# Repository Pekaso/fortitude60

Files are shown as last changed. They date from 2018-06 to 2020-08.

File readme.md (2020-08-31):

# Fortitude60

Fortitude60

👊A 60% (12x5) split keyboard with staggerd column layout.👊

# Build Guide

## Fortitude60 v1.0(C94 Limited Edition)
[ビルドガイド（日本語）](Documents/buildguide_jp_v1.0.md)

[Build Guide (EN)](Documents/buildguide_en_v1.0.md)

## Fortitude60 v1.1(Yushakobo Ver.)
[ビルドガイド（日本語）](Documents/buildguide_jp_v1.1.md)

[Build Guide (EN)](Documents/buildguide_en_v1.1.md)

# Firmware Flashing
[ファームウェア書き込み方法（日本語）](Documents/firmware_flashing-jp_new.md)

[Firmware Flashing（EN）](Documents/firmware_flashing-en_new.md)

## F.A.Q
[よくある質問（日本語）](Documents/faq_jp.md)

[Frequently Asked Questions（EN）](Documents/faq_en.md)

# License

Released under the MIT license. see [LICENSE](https://github.com/Pekaso/fortitude60/blob/master/LICENSE)

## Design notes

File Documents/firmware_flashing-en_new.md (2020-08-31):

# Fortitude60 Firmware Burning Instructions (Latest Version)

## Burning Instructions for a Brand New MCU (Applicable for the first time only)
New MCUs do not have any firmware written to them. Follow the instructions below to write the firmware and settings data to the EEPROM for the first time.

These instructions assume you have the QMK Firmware build environment and a firmware burning application, such as AVRDude, installed on your computer.

### First-Time Burning Instructions (Linux, macOS, Msys2 on Windows)
1.  In the same way you would install any other QMK Firmware, navigate into the ``QMK Firmware`` directory and run the commands listed below:
To burn the firmware for the left-hand side of the keyboard: ``make fortitude60/rev1:default:avrdude-split-left``  
To burn the firmware for the right-hand side of the keyboard: ``make fortitude60/rev1:default:avrdude-split-right``

1. When you see the message, ``Detecting USB port, reset your controller now........`` during the build process, create a short between the Reset (RST) and GND pins on the MCU using a pair of tweezers. This will put the MCU into Write Mode. (Note: Be careful not to accidentally touch the nearby 5V pin!)

2. When you see the message, ``avrdude.exe done.  Thank you.``, the firmware has been written successfully.

If you are using Windows 10, after you have completed burning the firmware for the left-hand side of the keyboard, when you navigate to [Bluetooth and Other Devices], under [Settings]-[Devices], the keyboard will appear as ``The Fortitude60 Keyboard``.

settings

If you are using the Current QMK Firmware ([d1190df](https://github.com/qmk/qmk_firmware/commit/d1190df10be933c64fee648b41191131313020a2) or later, you will be able to use this same method to verify the right-hand side of the keyboard. If you are using an earlier version, you will see the message: **No device is recognized**

### Burning Instructions (Windows GUI) 
Please refer to the instructions in: 
[firmware_flashing-en.md#Burning Instructions (Windows)](/Documents/firmware_flashing-jp==en.md#BurningInstructionsWindows) .

## Typical Firmware Burning (Applies from the second time on)

The instructions for burning the firmware from the second time on are always the same. Simply run the following command:

``make fortitude60/rev1:default:avrdude``

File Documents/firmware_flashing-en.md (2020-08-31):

# Fortitude60 Firmware Burning Instructions（Old Version）
These steps are requierd to prepare a MCU for the first time, or to reset it back to the factory settings. If you have bought a v1.0 Kit, the keymap and essential settings have already been written to the MCU, so please proceed with the normal burning instructions (v1.0 users can skip the EEPROM section.) 

These instructions assume you have the QMK Firmware build environment and a firmware burning application, such as AVRDude, installed on your computer.

## Burning the EEPROM
Due to the hardware limitations of the Foritude 60, you must burn separate EEPROMs for the left-hand and right-hand sides of the keyboard, to help identify the devices. After you have written the EEPROM once, you do not need to do it again every time you update the QMK firmware. 

You can find the files that you need to write to the EEPROM in the following location:   
``/qmk_firmware/quantum/split_common``  

This is the file for the left-hand side: ``eeprom-lefthand.eep``  
This is the file forthe right-hand side: ``eeprom-righthand.eep``

### Burning Instructions (Linux)
To put the MCU into Write Mode, when the LED on the chip starts blinking, create a short between the Reset (RST) and GND pins on the MCU using a pair of tweezers, then execute the following commands. (Note: Be careful not to accidentally touch the nearby 5V pin!)

Command for Left-Hand Side of Keyboard:
``avrdude -c avr109 -p m32u4 -P /dev/ttyS1 -U  eeprom:w:"./quantum/split_common/eeprom-lefthand.eep``

Command for Right-Hand Side of Keyboard:
``avrdude -c avr109 -p m32u4 -P /dev/ttyS1 -U  eeprom:w:"./quantum/split_common/eeprom-righthand.eep``

Note: For your installation, replace ``/dev/tty*`` with the serial port name that appears when you reset the MCU.

### Burning Instructions (Windows)
Use AVRDude (GUI-baseed app) according to the directions indicated here:  
http://emizping.hatenablog.com/entry/2017/05/25/222653

This will allow you to burn both QMK firmwares at the same time. 

## Burning the QMK Firmware
You can burn the QMK Firmware for the0 Fortitude 60 in the same manner as any other keyboard: 

``make fortitude60/rev1:default:avrdude``

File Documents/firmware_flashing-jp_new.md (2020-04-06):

# Fortitude60 ファームウェア書き込み方法（最新版）

## 新品のMCUへの書き込み（初回のみ）
新品のMCUにはファームウェアが書き込まれていないため、下記の方法で初期ファームウェアとEEPROMへの設定データを書き込んで下さい。

以下はPCにQMK Firmwareのビルド環境及びAVRDUDEなどの書き込みツールが利用できるようになっていることを前提としています。

### 書き込み方法(Linux, macOS, Msys2 on Windows)
1. 通常のQMK Firmwareと同様に、qmk_firmware直下のディレクトリへ移動し、以下のコマンドを実行してください。  
左手側の書き込み: ``make fortitude60/rev1:default:avrdude-split-left``  
右手側の書き込み: ``make fortitude60/rev1:default:avrdude-split-right``

1. 途中で``Detecting USB port, reset your controller now........``という表示が出たら、MCU上のリセット（RST）ピンとGNDピンをピンセットなどでショート（隣に5Vがあるので注意！）させMCUを書き込みモードにします。

2. ``avrdude.exe done.  Thank you.``がでて正常に終了すれば完了です。

左手側を書き込んだあと、Windows10であれば[Windowsの設定]-[デバイス]の中の[Bluetoothとその他デバイス]欄に``The Fortitude60 Keyboard``というデバイスが認識されていれば成功です。

settings

~~右手側を書き込んだあと、**デバイスとして何も認識されない**のが正しい挙動になります。~~  
(現在のQMK Firmware([d1190df](https://github.com/qmk/qmk_firmware/commit/d1190df10be933c64fee648b41191131313020a2)以降)では右手側もデバイスとして認識されるようになりました。)

### 書き込み方法(Windows GUI)
[firmware_flashing-jp.md#書き込み方法windows](/Documents/firmware_flashing-jp.md#書き込み方法windows) を参照してください。

## 通常のファームウェアの書き込み（2回目以降）
2回目以降のファームウェアの書き換えは他のキーボードと同様に書き込んでください。

``make fortitude60/rev1:default:avrdude``

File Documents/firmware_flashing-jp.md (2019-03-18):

# Fortitude60 ファームウェア書き込み方法（旧版）
MCUを単体で新規購入したり、訳あって再度書き込みしたい場合の手順です。
キット付属品、キーマップ更新などの単純な書き込み時には不要です。通常通りの書き込みを行ってください。

以下はPCにQMK Firmwareのビルド環境及びAVRDUDEなどの書き込みツールが利用できるようになっていることを前提としています。

## EEPROM書き込み
Fortitude60はハードウェアの制約上、左右の識別にEPROMの書き込みが必要です。この手順は新品のMCUに初めて書き込む場合のみ必要です。また一度書き込んだ以降はQMKの書き換えごとに以下を行う必要もありません。

EEPROMに書き込むファイルは以下のディレクトリにあります。  
``/qmk_firmware/quantum/split_common``  

左手用 ``eeprom-lefthand.eep``  
右手用 ``eeprom-righthand.eep``

### 書き込み方法(Linux)
MCU上のリセット（RST）ピンとGNDピンをピンセットなどでショート（隣に5Vがあるので注意！）させLEDが明滅している間に以下のコマンドを実行  

左手の例:   
``avrdude -c avr109 -p m32u4 -P /dev/ttyS1 -U  eeprom:w:"./quantum/split_common/eeprom-lefthand.eep``

左手の例:   
``avrdude -c avr109 -p m32u4 -P /dev/ttyS1 -U  eeprom:w:"./quantum/split_common/eeprom-righthand.eep``

``/dev/tty*``はリセットさせた際に出現するものに各自置き換えてください。

### 書き込み方法(Windows)
AVRDUDE（GUIツール）を使用した方法  
http://emizping.hatenablog.com/entry/2017/05/25/222653

QMKの書き込みも同時に行えるっぽい

## QMK Firmware書き込み
QMKは他のキーボードと同様に書き込んでください。

``make fortitude60/rev1:default:avrdude``

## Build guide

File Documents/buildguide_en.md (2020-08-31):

# Fortitude60 Build Guide
## Parts List

The parts list below describes the list of parts required to build both sides of the keyboard. If you would like to build one side of the keyboard only (single-handed keyboard), please divide the quantity in half.

|Part Name|Model Number|Quantity|Comments|
|---|----|----|----|
|PCB|Fortitude60 Main|2 boards|Included in kit|
|PCB Plate|Fortitude60 Plate|2 plates| Included in kit |
|Microcontroller (MCU)|Beetle USB 32u4|2 pieces | Included in kit (Refer to the “Firmware Burning” section below to find out if you need to burn the firmware yourself.)|
|USB Type-C Connector|AE-USB2.0-TYPE-C|2 pieces |Included in kit |
|Diodes |1N4148 100V200mA|60 pieces| Through-hole (lead type) diodes are included in the kit. You can also use the SMD equivalent, if you prefer. |
|Tactile Switches|2.54mm Pitch|2 pieces| Included in kit|
|TRRS Jack|MJ-4PP-9|2 pieces|Included in kit|
|Rubber Feet|2 large feet + 2 small feet| 4 pieces total|Included in kit|
|TRRS Cable|4-core cable|1 cable|You may use a 3-core calbe if you do not wish to use the [^underglow]function|
|Keyswitches|Cherry MX-compatible|60 pieces|Please select “PCB Mount” option (with pins)|
|Keycaps|Cherry MX-compatible|60 pieces|Cherry-stem compatible|

[^underglow]: Underglow, etc. Backlight and Underglow are treated as separate functions in the MCU.

The parts listed below help you enable optional features, and are not required for basic operation of the keyboard.

|Part Name|Model Number|Quantity|Comments|
|---|----|----|----|
|LED|3mm Bullet Type (Vf=1.4V, 8mA)|60 Pieces|Required if you want to enable the Backlight function|
|Resistor|470ohm, Through Hole (Lead Type) or 3216 (Surface Mount)|60 Pieces|Required if you want to enable the Backlight function|
|Resistor|1kohm, Through Hole (Lead Type) or 3216 (Surface Mount)|2 Pieces|Required if you want to enable the Backlight function|
|Resistor|5.1kohm, Through Hole (Lead Type)|2 Pieces|Required if you are planning on using a USB Type-C to Type-C cable|
|FET|IRLML6344TRPbF(Nch MOSFET)|2 Pieces|Required if you want to enable the Backlight function|
|------|----|----|----|
|LED Tape Light|WS2812B(Full Color LED)|2 Units|Required if you want to enable the Underglow function|
|Wire|Soft(bendable) wire|A few centimeters (or as much as is needed to prevent stress on parts) |Required if you want to enable the Underglow function

## Required Tools

|Part Name|Comments|
|---|----|
|Soldering Iron| A “ceramic heater” type is easy to use. We recommend the “HAKKO FX-600” model|
|Solder|  We recommend “Sparkle Solder” (スパークルハンダ) from the brand “Senju Metals” (千住金属工業)|
|Nipper|We recommend a type that does not produce a gap when close the blade. You can confirm this by closing the blade and then holding it over a light. |
|Tweezers|HOZAN P-891 tweezers are thick and easy to use!|
|Multimeter|Choosing a multimeter with Continuity Check and Diode Testing functions will help make this job much easier.|
|Masking Tape|This can help you temporarily hold pieces in places during the building phase.|
|An Unbreakable Spirit|Please be careful to avoid injury during construction (especially burns from soldering) 👊|

## Assembly

Printed Circuit Boards

Please arrange the circuit boards as indicated in the photograph to identify the left and right sides. In this guide, we will refer to the surface of the PCB to which the keyswitches will be attached to as the "Switch Side" and the surface to which the diodes will be attached  as the "Parts Side".

### Attaching the Diodes

Diodes（Through-Hole / Lead Type）  

Diodes（SMD）

Begin by attaching the diodes to the Parts Side of the PCB, in the mounting locations indicated in Red. For through-hole (lead type) diodes, the part will sit on the Parts Side and the solder should be applied on the Switch Side. For surface-mount diodes, both the solder and part should be applied on the Parts Side. Diodes require the correct polarity to function, so please install the diodes in accordance with the direction markings printed on the circuit board.  In the case that some of the markings are not not fully visible, please be assured that all of them are printed in the same direction on a single board.
(If you are lining up with your board with the photograph, please make sure the marks are pointing downwards.)

You can check that you soldered the diodes to the board correctly by using the "Diode Check" function on your multimeter.

### Attaching the TRRS Jack and Tactile Switch

TRRS&Switch

Align the TRRS jack and tactile switch with their markings on the Parts Side of the board and apply the solder on the Switch Side.

On the v1.0 revision of the PC, the footprint is too small, so you will need to mount the part with one of the pins bent. Begin soldering from the bent pin and then verify all of the connections. On the v1.1 revision of the PCB, this problem has been fixed, so you do not need to bend any pins. On the left-hand half of the keyboard, you can find the PCB version on the Switch Side. On the right hand side, you can find it on the bottom left of the Parts Side.

### (Optional) adding the LEDs for the Backlight

Backlight Parts

Start by attaching the resistors for the LEDs to the Parts Side of the PCB. For Through-Hole (Lead Type) resistors, you will apply the solder from the Switch Side. For SMD resistors, both the part and the solder will be attached to the Parts Side. Resistors do not have polarity, so you do not need to worry about the direction they are placed in. Please note that the resistance value will be different only in one position.

After you have finished soldering the resistors, please use your multimeter to verify their resistance.

Next, you need to attach the FET driver for the LEDs. Since it is a Surface Mount Device, it will be hard to attach. We suggest soldering one leg in place first, then getting to the others. 

### Attaching the Pin Headers

MCU Pin Header

MCU Soldered Pin Header

USB Pin Header

The MCU (Microcontroller) and USB Connector will be attached directly to the pin headers. You will need to separate the pin headers so that each section has enough pins to match the number of holes on each device. You will apply the solder on the Switch Side of the PCB. On each PCB, you will need to solder 3 sets of 6 pins for the MCU, and 2 sets of 2 pins for the USB connector.

``[Caution] Please do not solder the MCU yet!!! You still have a few more steps to complete first.``

### Attaching the Keyswitches

Attaching the Keyswitches

You may now begin attaching the keyswitches. Bring the keyswitches through the plate and then align them with the Switch Side of the main PCB. The keystem should extend out of the top of the plate. Please make sure you can see the legs of the switches through the holes on the Parts Side of the PCB, and that they are not bent. As shown in the photograph, during this stage, if you if you also attach part of the case to the PCB  (lightly), soldering will become much easier. Please note: If you attach all of the case at this point, later disassembly will become very difficult. 

Once you have completed checking everything, you can begin soldering the keyswitches from the Parts Side of the PCB.

（Optional）If you will be installing LEDs for the Backlight, the round holes are for the Anode (+) and the square-shaped holes are for the cathode (-). 

### Preparing the MCU

Identifying the MCUs

In the C94 Limited Edition version of the kit (v1.0), the MCU come with the Test Firmware already burned on the device. To keep track of which part will be used for the left-hand side of the keyboard, we attach a yellow sticker to one of the MCUs, as indicated in the photograph.

At this point, you are ready to solder the USB connector to the MCU. To begin, cut out 4 wires that are approximately 5~6cm in length. On both pieces, strip the coating by about 2mm and tin the wires ("tinning" is the process of preparing wires for soldering by applying a small amount of solder to them directly). After this, you will solder the USB Connector to the MCU, with the wires in the middle, as shown in the photograph. Be very careful to confirm that the correct pins are connected to the USB Connector, as a mistake could damage your PC. Perform this check on the MCU as well, since the same error is possible there too.  

For final confirmation, use the "Continuity Test" function on your multimeter to verify that the USB Connector's GND pin is continuous with the MCU's GND pin.

（Optional）A Power LED is attached to the MCU at the position on its circuit board marked with the letter "P". This could be quite bright. If you decide to install the other LEDs on this surface of the keyboard, the colors could interfere with each other. If you would like to prevent this effect, you can remove the Power LED from the MCU's circuit board. 

### Attaching the USB Connector to the MCU

Solder the USB Connector to the Parts Side of the PCB. The USB Connector does not require any specific mounting direction.

Begin by aligning the markings on the Main PCB (ex, 3V3) in the same directions as the markings on the MCU. The footprint of the keyboard is tight, so it is possible to attach the two without solder, however you may run into issues arising from loose or failing contacts. To fix these problems, please consider soldering the connection.

### Optional) Attaching LED Tape for the Underglow Function

If you would like to add Underglow to the unit, please wire LED Tape onto the Main PCB.

### Assembling the Case

The acrylic case is designed with tight fittings, in order to increase its strength when fully assembled (and reduce the need for screws. To begin installation, remove the protective sheets from the acrylic pieces and begin putting together the pieces as shown in the assembly diagram. The longer, mostly flat edges should be at the top of the keyboard, while the uneven edges (the ones with the teeth) should be at the bottom. None of the pieces have the same shape, so it should be difficult to make a mistake when assembling the pieces. If you still feel uncomfortable, try to fit the pieces lightly (without strong force). You may also use a file or sandpaper to adjust the pieces, if you feel it is necessary. Please pay extra attention to pieces that connect to each other, as they can break easily. (The connection for pieces A and B is particularly sensitive, so please attach these pieces first). 

You can now attach the bottom cover of the case. 
By attaching the rubber feet to the cover, you can produce a slight inclination in the keyboard. When you need to disassemble the keyboard, you can do as by inserting a small, dull, pointed object in the gap around the USB connector. This should be one of the easier ways to remove the case.

### Complete!

## Burning the QMK Firmware

A Test Version of the Firmware is available, and you may use it without modification. For the v1.0 revision, it comes pre-burned on the MCU's. For later revisions, you will need to burn it yourself. 

 If you would like to use the optional functions or customize the keymappings, you will need to modify the firmware, as indicated below. You can find the FORTITUDE60 version of the QMK firmware here: 
[https://github.com/qmk/qmk_firmware/tree/master/keyboards/fortitude60](https://github.com/qmk/qmk_firmware/tree/master/keyboards/fortitude60)

To learn how to build and customize QMK, please follow the official guide: [docs.qmk.fm](https://docs.qmk.fm/) 

2. Customizing the Keymap

Please use the values in  ` ` `keymap.c` ` ` in the ` ` `/keymaps/default/` ` ` folder as reference for editing your own keymap. 

2. Enabling the Backlight Function

Add ` ` `BACKLIGHT_ENABLE = yes` ` ` to ` ` `/keymaps/[your keymap]/rules.mk` ` `

This can't be used at the same time as the Underglow function.

2. Enabling the Underglow Function

Add ` ` `RGBLIGHT_ENABLE = yes` ` ` to 
` ` `/keymaps/[your keymap]/rules.mk` ` `

This can not be used at the same time as the Backlight function.

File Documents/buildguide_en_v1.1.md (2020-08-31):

# Fortitude60 v1.1（Yushakobo Ver.) Build Guide

## Parts

### Parts Included in Kit

The parts list below describes the list of parts included in the kit. There are enough parts to build for both sides of the keyboard. If you would like to build one side of the keyboard only (single-handed keyboard), please divide the quantity in half.

|Part Name|Model Number|Quantity|Comments|
|---|----|----|----|
|PCB|Fortitude60 Main|2 boards|Included in kit|
|PCB Plate|Fortitude60 Plate|2 plates| Included in kit |
|Microcontroller (MCU)|Beetle USB 32u4|2 pieces | Included in kit (Refer to the “Firmware Burning” section below to find out if you need to burn the firmware yourself.)|
|USB Type-C Connector|AE-USB2.0-TYPE-C|2 pieces |Included in kit |
|Diodes |1N4148 100V200mA|60 pieces| Through-hole (lead type) diodes are included in the kit. You can also use the SMD equivalent, if you prefer. |
|Tactile Switches|2.54mm Pitch|2 pieces| Included in kit|
|TRRS Jack|MJ-4PP-9|2 pieces|Included in kit|
|Rubber Feet|2 large feet + 2 small feet| 4 pieces total|Included in kit|

### Required Parts Not Included in Kit

The parts listed below are required to finish building a functioning keyboard, please acquire them yourself.

|Part Name|Model Number|Quantity|Comments|
|---|----|----|----|
|Keyswitches|Cherry MX-compatible|60 pieces|Please select “PCB Mount” option (with pins)|
|Keycaps|Cherry MX-compatible|60 pieces|Cherry-stem compatible|
|USB Cable|Type-C compatible|1 cable|If you plan on using a Type-C to Type-C cable, you will also need to buy a resistor, described later in the guide. |
|TRRS cable|4-pole cable|1 cable|
|Wire|Soft(bendable) wire | Approx. 60cm|Required to connect the MCU and USB connector.|

## Required Tools

|Part Name|Comments|
|---|----|
|Soldering Iron| A “ceramic heater” type is easy to use. We recommend the “HAKKO FX-600” model|
|Solder|  We recommend “Sparkle Solder” (スパークルハンダ) from the brand “Senju Metals” (千住金属工業)|
|Nipper|We recommend a type that does not produce a gap when close the blade. You can confirm this by closing the blade and then holding it over a light. |
|Tweezers|HOZAN P-891 tweezers are thick and easy to use!|
|Multimeter|Choosing a multimeter with Continuity Check and Diode Testing functions will help make this job much easier.|
|Masking Tape|This can help you temporarily hold pieces in places during the building phase.|
|An Unbreakable Spirit|Please be careful to avoid injury during construction (especially burns from soldering) 👊|

## Firmware Burning

Except for the first production run of kits, **the MCU does not have the firmware already writen to the  device.** Please follow the insturctions below to burn the firmware to the device yourself.

[Fortitude60　“Firmware Burning Instructions”](/Documents/firmware_flashing-jp_new.md)

## Assembly

### Checking the Printed Circuit Boards (PCB's)

Printed Circuit Boards

Please arrange the circuit boards as indicated in the photograph to identify the left and right sides. In this guide, we will refer to the surface of the PCB to which the keyswitches will be attached to as the "Switch Side" and the surface to which the diodes will be attached  as the "Parts Side".

### (Mounting Locations for Small Parts)

Imgur

This diagram includes the locations for the optional LEDs。The opposite half of the keyboard has the same layout. (This photograph is from the v1.0 PCB, but the mounting locations are the same on the newer versions.)

### Attaching the Diodes

Diodes（Through-Hole / Lead Type）

Diodes（SMD）

Begin by attaching the diodes to the Parts Side of the PCB, in the mounting locations indicated in Red. For through-hole (lead type) diodes, the part will sit on the Parts Side and the solder should be applied on the Switch Side. For surface-mount diodes, both the solder and part should be applied on the Parts Side. Diodes require the correct polarity to function, so please install the diodes in accordance with the direction markings printed on the circuit board.  In the case that some of the markings are not not fully visible, please be assured that all of them are printed in the same direction on a single board.
(If you are lining up with your board with the photograph, please make sure the marks are pointing downwards.)

You can check that you soldered the diodes to the board correctly by using the "Diode Check" function on your multimeter.

### Attaching the TRRS Jack and Tactile Switch

TRRS&Switch

Align the TRRS jack and tactile switch with their markings on the Parts Side of the board and apply the solder on the Switch Side.

Soldering Location

(The image shows the v1.0 revision of the PCB. The TRRS soldering points are the same on current revisions.）

Plug the TRRS cable into the jack and use the "Continuity Test" function on your multimeter to verify that each pin is contiuous (can conduct a signal.)

### Attaching the Pin Headers

MCU Pin Header

MCU Soldered Pin Header

USB Pin Header

The MCU (Microcontroller) and USB Connector will be attached directly to the pin headers. You will need to separate the pin headers so that each section has enough pins to match the number of holes on each device. You will apply the solder on the Switch Side of the PCB. On each PCB, you will need to solder 3 sets of 6 pins for the MCU, and 2 sets of 2 pins for the USB connector.

`` [Caution] Please do not solder the MCU yet!!! You still have a few more steps to complete first. ``

### Attaching the Keyswitches

Attaching the Keyswitches

You may now begin attaching the keyswitches. Bring the keyswitches through the plate and then align them with the Switch Side of the main PCB. The keystem should extend out of the top of the plate. Please make sure you can see the legs of the switches through the holes on the Parts Side of the PCB, and that they are not bent. As shown in the photograph, during this stage, if you if you also attach part of the case to the PCB  (lightly), soldering will become much easier. Please note: If you attach all of the case at this point, later disassembly will become very difficult. 

Once you have completed checking everything, you can begin soldering the keyswitches from the Parts Side of the PCB.

（Optional）If you will be installing LEDs for the Backlight, the round holes are for the Anode (+) and the square-shaped holes are for the cathode (-). 

### Preparing the MCU

Identifying the MCUs

To keep track of which part will be used for the left-hand side of the keyboard, we attach a yellow sticker to one of the MCUs, as indicated in the photograph.

### Additional Steps for Users Planning on Using USB Type-C Directly

Recently, the number of notebooks PCs that only come with a USB Type-C connector, such as the MacBook, have been increasing. For users who will be using the Fortitude 60 with this type of PC, please attach 5.1kΩ Pull-Down Resistors to pins CC1 and CC2, so that your PC can identify the keyboard as a USB Type-C device.

### Connecting the USB Connector and the MCU

Prepared Lead Wires
USB to MCU

At this point, you are ready to solder the USB connector to the MCU. To begin, cut out 4 wires that are approximately 5~6cm in length. On both pieces, strip the coating by about 2mm and tin the wires ("tinning" is the process of preparing wires for soldering by applying a small amount of solder to them directly). After this, you will solder the USB Connector to the MCU, with the wires in the middle, as shown in the photograph. Be very careful to confirm that the correct pins are connected to the USB Connector, as a mistake could damage your PC. Perform this check on the MCU as well, since the same error is possible there too.  

For final confirmation, use the "Continuity Test" function on your multimeter to verify that the USB Connector's GND pin is continuous with the MCU's GND pin.

Power LED

（Optional）A Power LED is attached to the MCU at the position on its circuit board marked with the letter "P". This could be quite bright. If you decide to install the other LEDs on this surface of the keyboard, the colors could interfere with each other. If you would like to prevent this effect, you can remove the Power LED from the MCU's circuit board. 

### Attaching the USB Connector to the MCU

MCUonPCB

Solder the USB Connector to the Parts Side of the PCB. The USB Connector does not require any specific mounting direction.

Imgur

We will begin with the MCU for the left-hand side, which is identified in the picture with its yellow sticker (the sticker is not provided in the kit, but you can apply one yourself). Begin by aligning the markings on the Main PCB (ex, 3V3) in the same directions as the markings on the MCU. The footprint of the keyboard is tight, so it is possible to attach the two without solder, however you may run into issues arising from loose or failing contacts. To fix these problems, please consider soldering the connection. To make a stable solder point, many people like to attach the header to the PCB first and then apply the solder at the top of the MCU. 

After you have finished assembling the unit, you can verify that the orientation is correct by re-orienting the unit to match the photograph. The left-hand side should look similar to the photograph, with the sticker and correct parts visible. 

Repeat a similar process for the right side, making sure its result also matches the photograph correctly. Please be careful, as problems with the connection on either the left- or right-hand unit could cause a short circuit and result in damage to the keyboard or your PC.

### Assembling the Case

Case Assembly Diagram

The acrylic case is designed with tight fittings, in order to increase its strength when fully assembled (and reduce the need for screws. To begin installation, remove the protective sheets from the acrylic pieces and begin putting together the pieces as shown in the assembly diagram. The longer, mostly flat edges should be at the top of the keyboard, while the uneven edges (the ones with the teeth) should be at the bottom. None of the pieces have the same shape, so it should be difficult to make a mistake when assembling the pieces. If you still feel uncomfortable, try to fit the pieces lightly (without strong force). You may also use a file or sandpaper to adjust the pieces, if you feel it is necessary. Please pay extra attention to pieces that connect to each other, as they can break easily. (The connection for pieces A and B is particularly sensitive, so please attach these pieces first). 

Assembled Example

Rubber Feet

You can now attach the bottom cover of the case. 
By attaching the rubber feet to the cover, as shown in the picture, you can produce a slight inclination in the keyboard. When you need to disassemble the keyboard, you can do as by inserting a small, dull, pointed object in the gap around the USB connector. This should be one of the easier ways to remove the case.

### Complete

Great job!

# Adding the Backlight and Underglow Functions

Through an optional modification, you can add Backlight and Underglow functions to the Fortitude60. Please refer to the [Fortitude60 v1.0（C94 Limited Edition) Build Guide](/Documents/buildguide_jp_v1.0.md) for the additional part list and modification instructions。

# Keymapping for Default Firmware (Test Mode Firmware)

## “Normal" Layer

Default

The keys indicated in Red and Blue allow you to activate the 「LOWER」or「RAISE」layers by holding down the 「LOWER」or「RAISE」 key and the key for your desired layered action at the same time.

## Adjust Layer（LOWER+RAISE)

Adjust

By holding down the「LOWER」and「RAISE」keys at the same time, you can activate the Adjustment Layer (Please Note: it will only be active while you are holding down the keys.)

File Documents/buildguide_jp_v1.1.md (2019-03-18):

# Fortitude60 v1.1（Yushakobo Ver.) ビルドガイド
## 部品

### キットに付属しているもの
以下の部品表は両手分の数量です。片手だけ作りたいという物好きな方は数量を半分にしてください。

|部品名|型番|数量|メモ|
|---|----|----|----|
|PCB|fortitude60 main|2枚|キット付属|
|PCBプレート|fortitude60 plate|2枚|キット付属|
|MCU|beetle USB 32u4|2個|キット付属、デフォルトファーム書き込み済み|
|USB Type-C|AE-USB2.0-TYPE-C|2個|キット付属|
|ダイオード|1N4148 100V200mA|60個|リードタイプが付属、SMDでも可|
|タクトスイッチ|2.54mmピッチ|2個|キット付属|
|TRRSジャック|MJ-4PP-9|2個|キット付属|
|ゴム足|大2個小2個|4個|キット付属|

### 各自用意する必要があるもの
以下の部品表は動作に必要ですがキットに付属しないため各自用意してください。

|部品名|型番|数量|メモ|
|---|----|----|----|
|キースイッチ|Cherry MX系|60個|PCBマウント対応|
|キーキャップ|Cherry MX系|60個|PCBマウント対応|
|USBケーブル|Type-C対応|1個|Type-C to Type-Cケーブル使用時は別途抵抗が必要となります。|
|TRRSケーブル|4極ケーブル|1本| |
|配線材|柔らかめのもの|60cmぐらい|MCUとUSBコネクタ間配線用|

## 必要な工具

|部品名|メモ|
|---|----|
|はんだごて|セラミックヒータータイプが使いやすいです。HAKKO FX-600がおすすめ|
|はんだ|千住金属工業のスパークルハンダが個人的におすすめです|
|ニッパー|刃を閉じて光にかざしたときに隙間がないのを選びましょう|
|ピンセット|HOZAN P-891が肉厚で使いやすいです。|
|テスター|導通チェッカー機能とダイオード確認機能がついていると便利|
|マスキングテープ|仮止め用|
|折れない心|やけどなど怪我には気をつけましょう👊|

## ファームウェアの書き込み
初回販売分を除き、MCUには **ファームウェアが書き込まれていません。** 以下の説明に従って各自書き込みを行ってください。

[Fortitude60　ファームウェア書き込み方法](/Documents/firmware_flashing-jp_new.md)

## 組み立て

### 基盤の確認

基板

基板を写真のように並べ左手側と右手側を決めます。以降の説明ではキースイッチを取り付ける面をスイッチ面、ダイオードを取り付ける面を部品面とします。

### (細かい部品の実装箇所)
Imgur
オプションのLEDを含んだ図。反対側も同じです。(写真はv1.0のものですが実装箇所は同じです。)

### ダイオードの取り付け

ダイオード（リード）  
ダイオード（SMD）

ダイオードは部品面（赤色実装箇所）に取り付けます、リードタイプはスイッチ面からはんだ付け、SMDは部品面からはんだ付けしてください。
ダイオードは部品に方向があり、基板上のマークの矢印方向にマークを合わせて実装します。
一部シルクにマークが潰れていますがすべて同じ方向になります。
（写真のように基板を置いたのであれば全部下向きにマークを揃えてください。）

テスターのダイオードモードでチェックし、はんだ付けができていることを確認します。

### TRRSジャック、タクトスイッチの取り付け

TRRS&SW

TRRSジャックとタクトスイッチは部品面のシルクに合わせて取り付け、スイッチ面からはんだ付けします。

はんだ付け箇所
（画像はPCB v1.0のものです。TRRSジャックのはんだ付け箇所は同じです。）

TRRSケーブルを接続し、それぞれの対称のピンが導通していることを導通チェッカーで確認します。

### ピンヘッダの取り付け

MCUピンヘッダ
MCUピンヘッダはんだ付け
USBピンヘッダ

MCU（コントローラー）とUSBコネクタを取り付けるピンヘッダを取り付けます。ピン数に合わせてピンヘッダを切断し、部品面に取り付けスイッチ面からはんだ付けします。片手のPCBにはMCUへは6ピンを3つ、USBコネクタには2ピンを2つずつはんだ付けします。

```[注意]まだこの時点ではMCUをはんだ付けしません！！！```

### キースイッチの取り付け

![キースイッチの取り付け](https://i.imgur.com/TzgloSK.jpg)

キースイッチを取り付けます。プレートにキースイッチをはめ込みながらスイッチ面に取り付けます。部品面の穴からすべての足が折り曲がらずに見えていることを確認してください。
スイッチを取り付ける際に写真のようにケースの一部分を軽くはめるとはんだ付けしやすいです（完全にはめたりすべてのケースを組んでしまうと分解が大変です）。
確認が終わったら部品面からはんだ付けします。

（オプション）Backlight用LEDを取り付ける場合には、スルーホールが丸い穴がアノード（＋）で四角い方がカソード（-）になります。

### MCUの準備

![MCUの区別](https://i.imgur.com/rGWsc2V.jpg)
以降（説明のため）写真で黄色いシールがついてるものが左手側のMCUとして進めます。

### USB-Type Cで使用する場合
MacBookなど最近のノートPCではType-Cコネクタのみのものが増えています。そんなPCでFortitude60を使いたい場合には、USB Type-Cコネクタ側にデバイスであることをPCに通知するためにCC1とCC2ピンを5.1kΩ抵抗でプルダウンしてください。

### USBコネクタとMCUの接続
![リード線の加工](https://i.imgur.com/TmkKmtx.jpg)  
![USBtoMCU](https://i.imgur.com/1KG1w1b.jpg)

USBコネクタとMCUをはんだ付けします。配線材を5~6cmほどの長さに4本切り出し、両端の被覆を2mm程度剥き予備ハンダをします。その後にUSBコネクタとMCUを写真のようにはんだ付けします。ピンを間違えると接続したPCを破壊する可能性があるので気をつけてください。もう片方のMCUにも同様に処理をします。

念の為テスターでUSBコネクタのGNDとMCUのGNDを導通チェックします。

![PwerLED](https://i.imgur.com/vUIUgq7.jpg)

（オプション）MCUにはPのシルクで電源LEDが実装されており、これが割と明るいため別にLEDを実装した場合は色が混ざったりするため必要な人はLEDを取り外すことをおすすめします。

### USBコネクタとMCUの取り付け

![MCUonPCB](https://i.imgur.com/456zKTy.jpg)

USBコネクタを部品面にはんだ付けします。USBコネクタに取り付け方向はありません。

![Imgur](https://i.imgur.com/G5kPgvn.jpg)

MCUはシールが貼ってあるものが左手側となり、基板上のシルクの表記（3V3など）とMCUのシルクを合わせた向きで組み込みます。フットプリントをきつめに設計しているためはんだ付けしなくても動作は可能ですが、ゆるい場合や一部接触不良になる場合ははんだ付けしてください。

組み込まれるとキーボードをひっくり返した時に"左手側"のシールのみが見えるのが正しい向きです。間違えるとショートするので気をつけてください。

### ケースの組み立て

![ケース組み立て図](https://i.imgur.com/tCJ72Rt.png)

アクリルケースは箱組の強度を上げるため寸法をきつく設計しています。アクリルの保護シートを剥がし画像のように組み立ててください。平坦な長辺がキーボードの上側で、凹凸がある長辺が下に来ます。片手の中に同じ形をした部品は無いため間違った場所には嵌らないようになっています。少しでも違和感を覚えたら力任せに嵌めずに場所を確認し、必要に応じてヤスリで調整するなどしてください。特に隣の辺と組み合わさる部分は割れやすいので気をつけてください。（特にAとBが組み込みづらい上に割れやすいので一番先に組むのがおすすめです。）

![組み立て例](https://i.imgur.com/5FMGbSL.jpg)

![ゴム足](https://i.imgur.com/mKuVylI.png)

最後に底蓋を嵌めこみます。底蓋にはゴム足を写真のように取り付けると少し傾斜ができます。逆に分解する場合にはUSBコネクタ部分の隙間に棒などを差し込んでてこの原理で外すとやりやすいです。

### 完成
お疲れ様でした。

# Backlight, Underglow機能の追加
Fortitude60はBacklightまたはUnderglow機能を追加することができます。改造するために必要な部品や改造方法は [Fortitude60 v1.0（C94 Limited Edition) ビルドガイド](/Documents/buildguide_jp_v1.0.md)を参照してください。

# テスト用ファームのキーマップ

## 通常レイヤー
![Default](https://i.imgur.com/LwIhpyb.png)

キーの赤色と青色で示された部分は「LOWER」と「RAISE」それぞれとの同時押しで実現するレイヤーになります。

## Adjustレイヤー（LOWER+RAISE)
![Adjust](https://i.imgur.com/SxD5wZX.png)

「LOWER」と「RAISE」を同時押しするとキーボードの設定を変えられるAdjustmentレイヤーになります（押している間のみ）。

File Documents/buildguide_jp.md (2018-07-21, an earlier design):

# Fortitude60 ビルドガイド
## 部品

以下の部品表は両手分の数量です。片手だけ作りたいという物好きな方は数量を半分にしてください。

|部品名|型番|数量|メモ|
|---|----|----|----|
|PCB|fortitude60 main|2枚|キット付属|
|プレート|fortitude60 plate|2枚|キット付属|
|MCU|beetle USB 32u4|2個|キット付属、デフォルトファーム書き込み済み|
|USB Type-C|AE-USB2.0-TYPE-C|2個|AE-USB-MICRO-B-Dでも代用可|
|ダイオード|1N4148 100V200mA|60個|リードタイプ、SMDタイプでも可|
|タクトスイッチ|2.54mmピッチ|2個|キット付属|
|TRRSジャック|MJ-4PP-9|2個|キット付属|
|ゴム足|大2個小2個|4個|キット付属|
|TRRSケーブル|4極ケーブル|1本|3極でも可（ただし4極必要な機能[^underglow]が使えません）|
|キースイッチ|Cherry MX系|60個|PCBマウント対応|
|キーキャップ|Cherry MX系|60個|PCBマウント対応|

[^underglow]: Underglow機能など。Backlight機能とUnderglow機能はMCUの仕様上排他となります。

以下の部品表はオプションです。必ずしも動作に必要ではありません。

|部品名|型番|数量|メモ|
|---|----|----|----|
|LED|3mm砲弾型(Vf=1.4V, 8mA)|60個|Backlight機能|
|抵抗|470ohm, リードまたは3216|60個|Backlight機能|
|抵抗|1kohm, リードまたは3216|2個|Backlight機能|
|FET|IRLML6344TRPbF(Nch MOSFET)|2個|Backlight機能|
|------|----|----|----|
|テープLED|WS2812B(フルカラーLED)|2本|Underglow機能|
|配線材|柔らかめのもの|適量|Underglow機能|

## 必要な工具

|部品名|メモ|
|---|----|
|はんだごて|セラミックヒータータイプが使いやすいです。HAKKO FX-600がおすすめ|
|はんだ|住友金属工業のスパークルハンダが個人的におすすめです|
|ニッパー|刃を閉じて光にかざしたときに隙間がないのを選びましょう|
|ピンセット|HOZAN P-891が肉厚で使いやすいです。|
|テスター|導通チェッカー機能とダイオード確認機能がついていると便利|
|マスキングテープ|仮止め用|
|折れない心|やけどなど怪我には気をつけましょう👊|

## 組み立て

基板を写真のように並べ左手側と右手側を決めます。以降の説明ではキースイッチを取り付ける面をスイッチ面、ダイオードを取り付ける面を部品面とします。

### ダイオードの取り付け

ダイオードは部品面に取り付けます、リードタイプはスイッチ面からはんだ付け、SMDは部品面からはんだ付けしてください。
ダイオードは部品に方向があり、基板上のマークの矢印方向にマークを合わせて実装します。
一部シルクにマークが潰れていますがすべて同じ方向になります。

テスターのダイオードモードで写真の部分をチェックし、はんだ付けができていることを確認します。

### TRRSジャック、タクトスイッチの取り付け

TRRSジャックとタクトスイッチは部品面のシルクに合わせて取り付け、スイッチ面からはんだ付けします。
（PCB v1.0）フットプリントの不備により、ピンを1本ずらして実装する必要があります。曲げたピンからはんだ付けして固定されることを確認してください。

TRRSケーブルを接続し、それぞれの対称のピンが導通していることを導通チェッカーで確認します。

### Backlight用LED用部品の取り付け（オプション）

バックライトLEDの抵抗を部品面に取り付けます。リードタイプはスイッチ面からはんだ付け、SMDは部品面からはんだ付けしてください。
部品に極性はありません。1箇所のみ抵抗値が異なるので気を付けてください。

はんだ付け後にはテスターで抵抗値を確認しましょう。

LEDを駆動するためのFETを部品面に取り付けます。表面実装部品のため実装難易度が高いですが、1箇所予備ハンダをして先に固定してしまえば楽になります。

### ピンヘッダの取り付け

MCU（コントローラー）とUSBコネクタを取り付けるピンヘッダを取り付けます。ピン数に合わせてピンヘッダを切断し、部品面に取り付けスイッチ面からはんだ付けします。片手のPCBにはMCUへは6ピンを3つ、USBコネクタには2ピンを2つずつはんだ付けします。

```[注意]まだこの時点ではMCUをはんだ付けしません！！！```

### キースイッチの取り付け

キースイッチを取り付けます。プレートにキースイッチをはめ込みながらスイッチ面に取り付けます。部品面の穴からすべての足が折り曲がらずに見えていることを確認してください。
スイッチを取り付ける際に写真のようにケースの一部分を軽くはめるとはんだ付けしやすいです（完全にはめたりすべてのケースを組んでしまうと分解が大変です）。
確認が終わったら部品面からはんだ付けします。

（オプション）Backlight用LEDを取り付ける場合には、スルーホールが丸い穴がアノード（＋）で四角い方がカソード（-）になります。

### MCUの準備

（C94 Limited Edition）MCUはテスト用のファームウェアが書き込み済みであり、下の写真のようにシールが貼られている方が左手側のMCUとなります。

USBコネクタとMCUをはんだ付けします。配線材を5~6cmほどの長さに4本切り出し、両端の被覆を2mm程度剥き予備ハンダをします。その後にUSBコネクタとMCUを写真のようにはんだ付けします。ピンを間違えると接続したPCを破壊する可能性があるので気をつけてください。もう片方のMCUにも同様に処理をします。

念の為テスターでUSBコネクタのGNDとMCUのGNDを導通チェックします。

（オプション）MCUにはPのシルクで電源LEDが実装されており、これが割と明るいため別にLEDを実装した場合は色が混ざったりするため必要な人はLEDを取り外すことをおすすめします。

### USBコネクタとMCUの取り付け

USBコネクタとMCUを部品面にはんだ付けします。USBコネクタに取り付け方向はありません。

MCUはマークが入っているものが左手側となり、基板上のシルクとMCUのシルクを合わせた向きで組み込みます。フットプリントをきつめに設計しているためはんだ付けしなくても動作は可能ですが、ゆるい場合や一部接触不良になる場合ははんだ付けしてください。

### Underglow用LEDテープの取り付け（オプション）

Underglowを追加する場合は、基板上にある「LED」の部分を基準に写真のように配線していきます。

### ケースの組み立て

アクリルケースは箱組の強度を上げるため寸法をきつく設計しています。アクリルの保護シートを剥がし以下の写真のように組み立ててください。片手の中に同じ形をした部品は無いため間違った場所には嵌らないようになっています。少しでも違和感を覚えたら力任せに嵌めずに場所を確認し、必要に応じてヤスリで調整するなどしてください。特に隣の辺と組み合わさる部分は割れやすいので気をつけてください。

最後に底蓋を嵌めこみます。底蓋にはゴム足を写真のように取り付けると少し傾斜ができます。逆に分解する場合にはUSBコネクタ部分の隙間に棒などを差し込んでてこの原理で外すとやりやすいです。

### 完成

## QMKファームウェアの書き込み

購入時点でテスト用ファームウェアが書き込まれているため、そのまま入力は可能です。キーマップのカスタマイズやオプション機能を使う場合は以下の手順で書き込んでください。
QMKのファームウェアのFORTITUDE60のキーボードは以下にあります。
[https://github.com/qmk/qmk_firmware/tree/master/keyboards/fortitude60](https://github.com/qmk/qmk_firmware/tree/master/keyboards/fortitude60)

2. キーマップのカスタマイズ

```/keymaps/default/```を参考に```keymap.c```を編集します。

2. Backlight機能の有効化

```/keymaps/[your keymap]/rules.mk```に```BACKLIGHT_ENABLE = yes```を追加します。

Underglow機能と両立はできません。

2. Underglow機能の有効化

```/keymaps/[your keymap]/rules.mk```の```RGBLIGHT_ENABLE = yes```を追加します。

Backlight機能と両立はできません。

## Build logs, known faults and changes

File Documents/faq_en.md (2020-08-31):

# Frequently Asked Questions

## Related to Parts

### How do I choose which LED to use？ Why is the electrical current value important?

If you would like to enable the Backlight function of the Fortitude60, it is designed around ```3mm Bullet-Type LEDs (Vf=1.4V, 8mA)```. This part is used as the basis for values used in the design, however, I think Red - Blue LEDs should also work fine. The electrical signals to the LEDs are driven through the FET, based on the VBUS and Vf values. To calculate the Current value (```If```), use the following calculation:  

```
If = (VBUS - Vf)/R
  = (5 - 1.4)/470
  = 0.00765...
  ≈ 8mA
```

When using different types of LEDs, you can use this calculation and the Vf value of your new LED to help you determine the new resistor value you need to match the current. 

### What kind of keyswitches should I use? Those with 3 pins or 5?

In addition to the 2 legs used to make the electrical contact for the keyswitch, there may be 1 - 3 more pins used to stabilize the part on the PCB, which results in  3 - 5 pins total. The PCB is designed with support for up to 5 pins, but you can use also 3 pin keyswitches. The plate for the Fortitude60 helps stabilize the keys, so that there will not be any difference in the typing sensation based on whether you use 3 or 5 pin switches. So, please use your favorite kind of keyswitches! 

## Related to Assembly

### I broke some of the acrylic pieces

The acrylic case for the Fortitude60 was designed with a very tight fit in mind. If you use excess force, it will crack. This being said, there are also times when you will to need to apply a little more force for more difficult pieces. Both the left and right side of the keyboard use the exact same pieces, so if you have trouble with the fit at first, try switching it with the matching part from the other side of the keyboard. If one of the pieces does break, contact me via ```@pekaso```on Twitter. I may be able to provide replacement parts, similar to the service some companies provide for plastic models.

### I Want to Use a Type-C to Type-C Cable

Recently, the number of notebooks PCs that only come with a USB Type-C connector, such as the MacBook, have been increasing. For users who will be using the Fortitude 60 with this type of PC, please attach 5.1kΩ Pull-Down Resistors to pins CC1 and CC2, so that your PC can identify the keyboard as a USB Type-C device.

https://twitter.com/Pekaso/status/1019570268505698305

## Related to Operation

### It doesn’t work, there’s a funny smell, and now my computer doesn’t work.

If the device can not be recognized as a keyboard, pull out the USB cable and check all the soldering points. Most importantly, check for a short between the 5V + GND on the USB side. Recent USB ports have a use a power supply safety device, but they can not protect against everything. I suggest testing the connection using the Continuity Test feature of your multimeter. If you would like to test further, try  plugging the keyboard into a USB hub, instead of directly into your computer. This is particularly useful for expensive computers.  ```Proceed with these steps at  your own risk.```

### If I connect only the right side into the USB port, it won’t work.

The Fortitude60 is designed for the  USB cable to plug into the left-hand half of the keyboard. In addition to this, due to the limits of the hardware, the firmware includes data to help it differentiate the left-hand and right-hand units. For these reasons, the right-hand unit can not be directly connected and recognized as a computer.

If you would like to verify the operation of the right-hand side of the keyboard only during assembly, connect the USB cable and then press the Reset button on the back of the device. This should make the MCU enter Write Mode and you should be able to see the unit as a serial device. If you would like to verify the operation of the keys, connect the right-hand side to the left-hand side via the TRRS cable.

If you would like to modify the unit so you can plug the USB into the right-side of the unit, you will need to modify the QMK firmware.

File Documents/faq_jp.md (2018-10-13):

# よくある質問

## 部品編

### LEDはどれを選べばいい？電流の値の意味は？

Fortitude60にBacklightをつける場合、LEDの選定の目安として```3mm砲弾型(Vf=1.4V, 8mA)```と指定してあります。ここで指定してあるVfと電流値は設計上指定したVfとそこから計算した目安の電流値のため、LEDに関しては赤から青までどれでも光ると思います。電気的には全てのLEDがFETを通してVBUSで駆動させるため流れる電流値```If```は、

```
If = (VBUS - Vf)/R
  = (5 - 1.4)/470
  = 0.00765...
  ≈ 8mA
```

ぐらいの気持ちです。

### キースイッチには3ピンと5ピンがあるけどどっちが使えるの？

キースイッチは接点の足2ピンに加えて、PCBに固定するためのピンが1本または3本あり、合計で3ピンと5ピンのものが存在します。設計上5ピンのものが使えるように穴が空けてあるため、3ピンのものも使用できます。Fortitude60はプレートでもしっかりキースイッチが固定されるためどちらでもそんなに打鍵感は変わりません。お好きなのをどうぞ

## 組み立て編

### アクリル割れちゃった

Fortitude60はキツキツな設計と穴だらけのアクリルケースのため、無理な力を加えるとあっけなく割れます。かといって及び腰でやっても嵌らないのである程度頑張る必要があります。左右の同じ箇所のパーツは同一の部品のため、嵌らないときは左右で交換してみると良いでしょう。もし割れてしまった場合は```@pekaso```まで連絡をください。ガンプラの部品よろしく個別に対応が出来るかもしれません。

### Type-C to Type-Cケーブルが使いたい

MacBookなど最近のノートPCではType-Cコネクタのみのものが増えています。そんなPCでFortitude60を使いたい場合には、USB Type-Cコネクタ側にデバイスであることをPCに通知するためにCC1とCC2ピンを5.1kΩ抵抗でプルダウンしてください。

https://twitter.com/Pekaso/status/1019570268505698305

## 動作編

### うごかない、なんか香ばしい匂いがする、パソコンが動かなくなった

キーボードとして動作しない場合は即座にUSBケーブルを引っこ抜いてはんだ付けを確認しましょう。特にUSBの+5VとGNDがショートしてないか指す前にも十分に確認してください。最近のUSBポートはデバイスの充電にも利用されることから電源の安全回路は強くなっていますが全てにおいて守ってくれるわけではないので注意してください。テスターなどで確実に動くことが確認できれば良いですが、えいやで動作確認する場合にはUSBハブを間に挟むと高価なパソコンの身代わりになってくれるかもしれません。```自己責任です。```

### 右手だけUSBポートにつないでも動かないんだけど

Fortitude60は設計上左手側にUSBケーブルを繋いで使用することを想定しています。これに加えてハードウェア上の制約のため予め書き込んであるファームウェアには左手と右手を区別するデータが埋め込まれているため、右手側単体を接続してもキーボードとしては動作しません。

もし組み立て途中で右手だけ動作確認したい場合はUSBケーブルで接続した後裏側のリセットボタンを押すとMCUが書き込みモードになり、シリアルデバイスが出現してくることを確認してください。キーなどの動作確認をしたい場合は左手とTRRSで接続してから行ってください。

もし右手側にUSBを刺して使用する場合にはQMKのファームウェア側の改造が必要です。

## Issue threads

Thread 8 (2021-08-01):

FET?

sipp11, 2021-08-01:
From the build guide, there is one FET on each side, but there is no mention anywhere in the guide. Does this FET a requirement for the board? and what is the part number? so I could buy and complete the build?

mtei, 2021-08-01:
see https://github.com/Pekaso/fortitude60/blob/master/Documents/buildguide_en_v1.1.md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

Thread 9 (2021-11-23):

Can you give a brief sentence explaining the difference between v1.0 and v1.1?

mcp292, 2021-11-23:

mcp292, 2021-11-24:
> On the v1.0 revision of the PC, the footprint is too small, so you will need to mount the part with one of the pins bent. Begin soldering from the bent pin and then verify all of the connections. On the v1.1 revision of the PCB, this problem has been fixed, so you do not need to bend any pins.

https://github.com/Pekaso/fortitude60/commit/f10d95edd2a41ee8b0e2233295cf5cd7911abea5
https://github.com/Pekaso/fortitude60/blob/master/Documents/buildguide_en_v1.0.md

mcp292, 2021-11-24:
Please let me know if this is the only change in revision_ v1.1.

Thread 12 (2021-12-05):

Build guide doesn't specify grounding CC1 and CC2

mcp292, 2021-12-05:
It just says to connect a pull-down resistor CC1 and CC2, which I would think means connect them together.

https://github.com/Pekaso/fortitude60/blob/master/Documents/buildguide_en_v1.1.md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

The [picture](https://camo.githubusercontent.com/b6e7f4433f16ff824712e0daa52107cf370357707a03732bab2b3cc2562c30f5/68747470733a2f2f692e696d6775722e636f6d2f47356b5067766e2e6a7067) says otherwise though.

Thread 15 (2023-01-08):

The following libraries were not found

nanpuhaha, 2023-01-08:
On KiCad 5.1.12,

```
The following libraries were not found:
- switches.lib
- relays.lib
- motors.lib
- transistors.lib
- conn.lib
- linear.lib
- regul.lib
- cmos4000.lib
- adc-dac.lib
- memory.lib
- xilinx.lib
- microcontrollers.lib
- dsp.lib
- microchip.lib
- analog_switches.lib
- motorola.lib
- texas.lib
- intel.lib
- digital-audio.lib
- philips.lib
- display.lib
- cypress.lib
- siliconi.lib
- opto.lib
- atmel.lib
- contrib.lib
- valves.lib
- C:\Users\kousuke\Documents\footprint_pekaso.lib
- C:\Users\kousuke\Downloads\Ergo42-master\Ergo42-master\ergo42\library\ergo42.lib
```
---

On KiCad 6.0.9,

```
The following libraries were not found:
- power.lib
- device.lib
- switches.lib
- relays.lib
- motors.lib
- transistors.lib
- conn.lib
- linear.lib
- regul.lib
- 74xx.lib
- cmos4000.lib
- adc-dac.lib
- memory.lib
- xilinx.lib
- microcontrollers.lib
- dsp.lib
- microchip.lib
- analog_switches.lib
- motorola.lib
- texas.lib
- intel.lib
- audio.lib
- interface.lib
- digital-audio.lib
- philips.lib
- display.lib
- cypress.lib
- siliconi.lib
- opto.lib
- atmel.lib
- contrib.lib
- valves.lib
- C:\Users\kousuke\Documents\footprint_pekaso.lib
- C:\Users\kousuke\Downloads\Ergo42-master\Ergo42-master\ergo42\library\ergo42.lib
```

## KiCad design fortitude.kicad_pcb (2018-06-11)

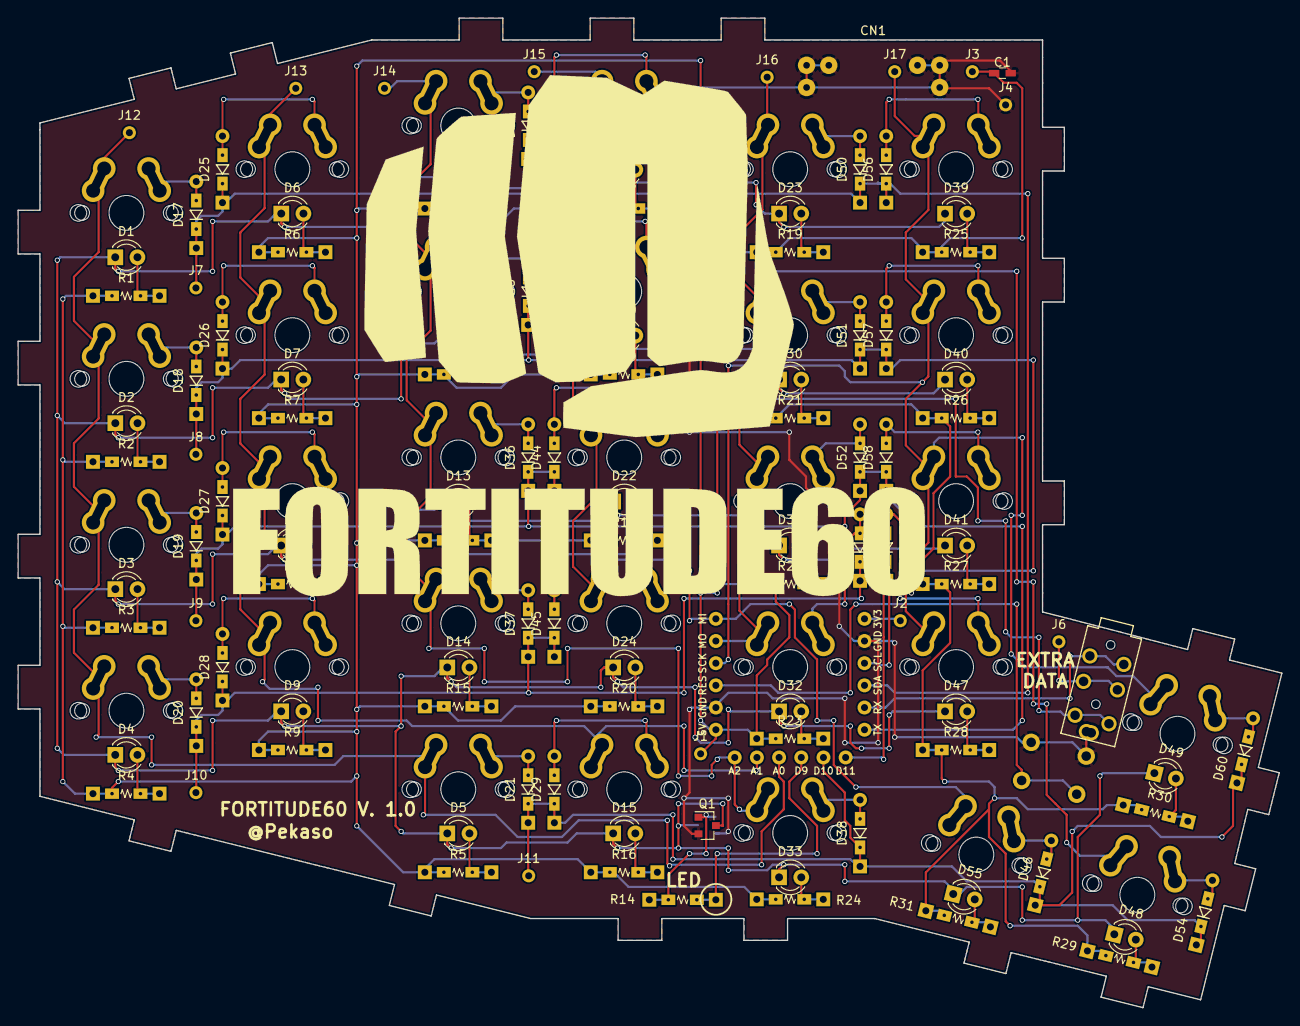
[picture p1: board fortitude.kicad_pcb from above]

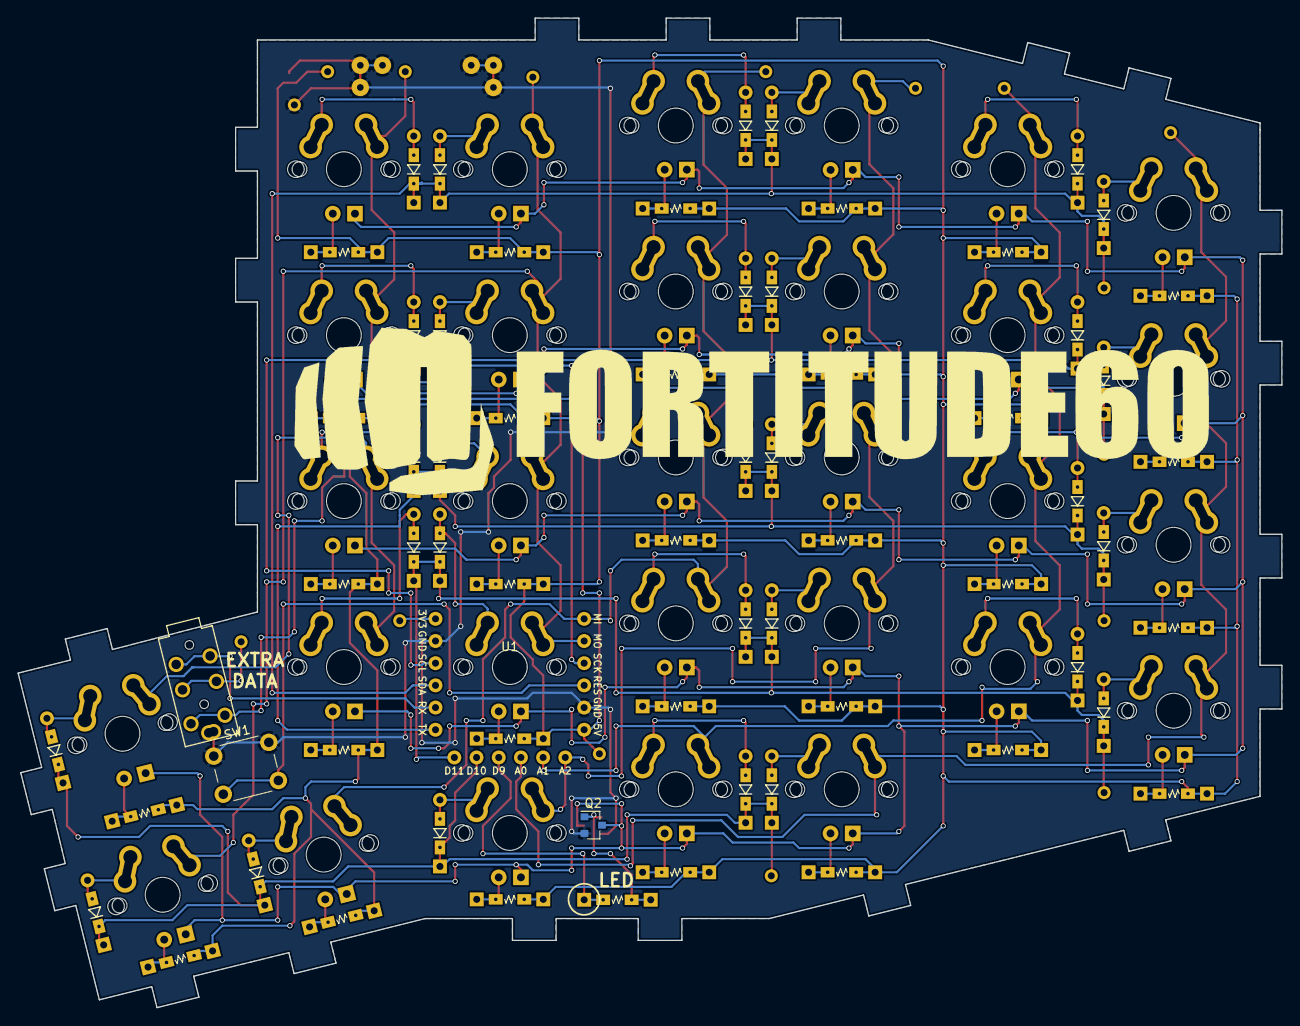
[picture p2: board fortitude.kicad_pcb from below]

Board: 2 copper layers, 144.7 x 113.3 mm, 144 parts (3 on the bottom side), 80 nets.

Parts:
C1: 0.1u; C_0603_HandSoldering
CN1: AE-USB2.0-TYPE-C-B
D1, D2, D3, D4, D5, D6, D7, D8, D9, D10, D11, D12, D13, D14, D15, D16, D22, D23, D24, D30, D31, D32, D33, D39, D40, D41, D47, D48, D49, D55: LED; LED_D3.0mm
D17, D18, D19, D20, D21, D25, D26, D27, D28, D29, D34, D35, D36, D37, D38, D42, D43, D44, D45, D46, D50, D51, D52, D53, D54, D56, D57, D58, D59, D60: 1N4148; Diode_SMD_THT_N
J1: 5V; Measurement_Point_Round-TH_Small
J2: 3V3; Measurement_Point_Round-TH_Small
J3: VBUS; Measurement_Point_Round-TH_Small
J4: GND; Measurement_Point_Round-TH_Small
J5: Audio-Jack-4; trrs_jack_r
J6: EX_DATA; Measurement_Point_Round-TH_Small
J7: ROW0; Measurement_Point_Round-TH_Small
J8: ROW1; Measurement_Point_Round-TH_Small
J9: ROW2; Measurement_Point_Round-TH_Small
J10: ROW3; Measurement_Point_Round-TH_Small
J11: ROW4; Measurement_Point_Round-TH_Small
J12: COL0; Measurement_Point_Round-TH_Small
J13: COL1; Measurement_Point_Round-TH_Small
J14: COL2; Measurement_Point_Round-TH_Small
J15: COL3; Measurement_Point_Round-TH_Small
J16: COL4; Measurement_Point_Round-TH_Small
J17: COL5; Measurement_Point_Round-TH_Small
Q1, Q2: IRLML6344TRPbF; SOT-23
R1, R2, R3, R4, R5, R6, R7, R8, R9, R10, R11, R12, R13, R15, R16, R17, R18, R19, R20, R21, R22, R23, R24, R25, R26, R27, R28, R29, R30, R31: 470; Resister_SMD_THT_N
R14: 1k; Resister_SMD_THT_N
SW1: RESET; SW_PUSH_6mm
SW2: SW_1_1; key_switch_mx
SW3: SW_1_2; key_switch_mx
SW4: SW_1_3; key_switch_mx
SW5: SW_1_4; key_switch_mx
SW6: SW_1_5; key_switch_mx
SW7: SW_2_1; key_switch_mx
SW8: SW_2_2; key_switch_mx
SW9: SW_2_3; key_switch_mx
SW10: SW_2_4; key_switch_mx
SW11: SW_2_5; key_switch_mx
SW12: SW_3_1; key_switch_mx
SW13: SW_3_2; key_switch_mx
SW14: SW_3_3; key_switch_mx
SW15: SW_3_4; key_switch_mx
SW16: SW_3_5; key_switch_mx
SW17: SW_4_1; key_switch_mx
SW18: SW_4_2; key_switch_mx
SW19: SW_4_3; key_switch_mx
SW20: SW_4_4; key_switch_mx
SW21: SW_4_5; key_switch_mx
SW22: SW_5_1; key_switch_mx
SW23: SW_5_2; key_switch_mx
SW24: SW_5_3; key_switch_mx
SW25: SW_5_4; key_switch_mx
SW26: SW_5_5; key_switch_mx
SW27: SW_6_1; key_switch_mx
SW28: SW_6_2; key_switch_mx
SW29: SW_6_3; key_switch_mx
SW30: SW_6_4; key_switch_mx
SW31: SW_6_5; key_switch_mx
U1: beetle

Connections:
COL1: J12.1, SW2.1, SW3.1, SW4.1, SW5.1, SW6.1, U1.10
COL2: J13.1, SW7.1, SW8.1, SW9.1, SW10.1, SW11.1, U1.11
COL3: J14.1, SW12.1, SW13.1, SW14.1, SW15.1, SW16.1, U1.12
COL4: J15.1, SW17.1, SW18.1, SW19.1, SW20.1, SW21.1, U1.18
COL5: J16.1, SW22.1, SW23.1, SW24.1, SW25.1, SW26.1, U1.17
COL6: J17.1, SW27.1, SW28.1, SW29.1, SW30.1, SW31.1, U1.16
GND: C1.2, CN1.1, J4.1, J5.4, Q1.2, Q2.2, SW1.1, U1.2, U1.14
LED: R14.2, U1.9
unnamed: D1.1, D2.1, D3.1, D4.1, D5.1, D6.1, D7.1, D8.1, D9.1, D10.1, D11.1, D12.1, D13.1, D14.1, D15.1, D16.1, D22.1, D23.1, D24.1, D30.1, D31.1, D32.1, D33.1, D39.1, D40.1, D41.1, D47.1, D48.1, D49.1, D55.1, Q1.3, Q2.3
unnamed: D1.2, R1.2
unnamed: D2.2, R2.2
unnamed: D3.2, R3.2
unnamed: D4.2, R4.2
unnamed: D5.2, R5.2
unnamed: D6.2, R6.2
unnamed: D7.2, R7.2
unnamed: D8.2, R8.2
unnamed: D9.2, R9.2
unnamed: D10.2, R10.2
unnamed: D11.2, R11.2
unnamed: D12.2, R12.2
unnamed: D13.2, R13.2
unnamed: D14.2, R15.2
unnamed: D15.2, R16.2
unnamed: D16.2, R17.2
unnamed: D17.2, SW2.2
unnamed: D18.2, SW3.2
unnamed: D19.2, SW4.2
unnamed: D20.2, SW5.2
unnamed: D21.2, SW6.2
unnamed: D22.2, R18.2
unnamed: D23.2, R19.2
unnamed: D24.2, R20.2
unnamed: D25.2, SW7.2
unnamed: D26.2, SW8.2
unnamed: D27.2, SW9.2
unnamed: D28.2, SW10.2
unnamed: D29.2, SW11.2
unnamed: D30.2, R21.2
unnamed: D31.2, R22.2
unnamed: D32.2, R23.2
unnamed: D33.2, R24.2
unnamed: D34.2, SW12.2
unnamed: D35.2, SW13.2
unnamed: D36.2, SW14.2
unnamed: D37.2, SW15.2
unnamed: D38.2, SW16.2
unnamed: D39.2, R25.2
unnamed: D40.2, R26.2
unnamed: D41.2, R27.2
unnamed: D42.2, SW17.2
unnamed: D43.2, SW18.2
unnamed: D44.2, SW19.2
unnamed: D45.2, SW20.2
unnamed: D46.2, SW21.2
unnamed: D47.2, R28.2
unnamed: D48.2, R29.2
unnamed: D49.2, R30.2
unnamed: D50.2, SW22.2
unnamed: D51.2, SW23.2
unnamed: D52.2, SW24.2
unnamed: D53.2, SW25.2
unnamed: D54.2, SW26.2
unnamed: D55.2, R31.2
unnamed: D56.2, SW27.2
unnamed: D57.2, SW28.2
unnamed: D58.2, SW29.2
unnamed: D59.2, SW30.2
unnamed: D60.2, SW31.2
unnamed: J2.1, U1.1
unnamed: J5.3, J6.1
unnamed: Q1.1, Q2.1, R14.1
unnamed: SW1.2, U1.15
ROW1: D17.1, D25.1, D34.1, D42.1, D50.1, D56.1, J7.1, U1.4
ROW2: D18.1, D26.1, D35.1, D43.1, D51.1, D57.1, J8.1, U1.3
ROW3: D19.1, D27.1, D36.1, D44.1, D52.1, D58.1, J9.1, U1.6
ROW4: D20.1, D28.1, D37.1, D45.1, D53.1, D59.1, J10.1, U1.7
ROW5: D21.1, D29.1, D38.1, D46.1, D54.1, D60.1, J11.1, U1.8
TXO: J5.2, U1.5
Vcc: C1.1, J1.1, J3.1, J5.1, R1.1, R2.1, R3.1, R4.1, R5.1, R6.1, R7.1, R8.1, R9.1, R10.1, R11.1, R12.1, R13.1, R15.1, R16.1, R17.1, R18.1, R19.1, R20.1, R21.1, R22.1, R23.1, R24.1, R25.1, R26.1, R27.1, R28.1, R29.1, R30.1, R31.1, U1.13

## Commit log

2018-06-11 add pcb data
    [fortitude.kicad_pcb, fortitude.sch]
2018-06-11 add case and readme
2018-08-08 少し手直し
2018-08-11 一部画像の修正とUnderglowオプションに追記
2018-08-15 はずかしいミスを修正
2018-10-24 add document for PCB v1.1 and above.
2018-10-24 Add the note for use the type-C to type-C cable.
2018-10-29 パーツの誤りを修正。
2019-01-19 Update buildguide_jp_v1.0.md
    QMKのファームでデフォルトではUndeglowが有効になってるのでQMKに合わせる
2019-07-29 update main-PCB and plate data
2020-04-06 split_common対応
    split_commonが導入されたら右手側もそのまま認識されるようになったので対応
